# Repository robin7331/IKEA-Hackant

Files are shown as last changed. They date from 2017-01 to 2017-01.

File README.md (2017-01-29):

# IKEA Hackant

A simple LIN slave attached to the stock controller board adds two memory buttons.
If you are interested in how this was developed check out my YouTube Tutorial

YouTube Tutorial (https://www.youtube.com/watch?v=AB75AxprXqQ "IKEA Bekant Table Hacking")

## Schematics

Simple schematics created with [Fritzing](http://fritzing.org/home/ "Fritzing").

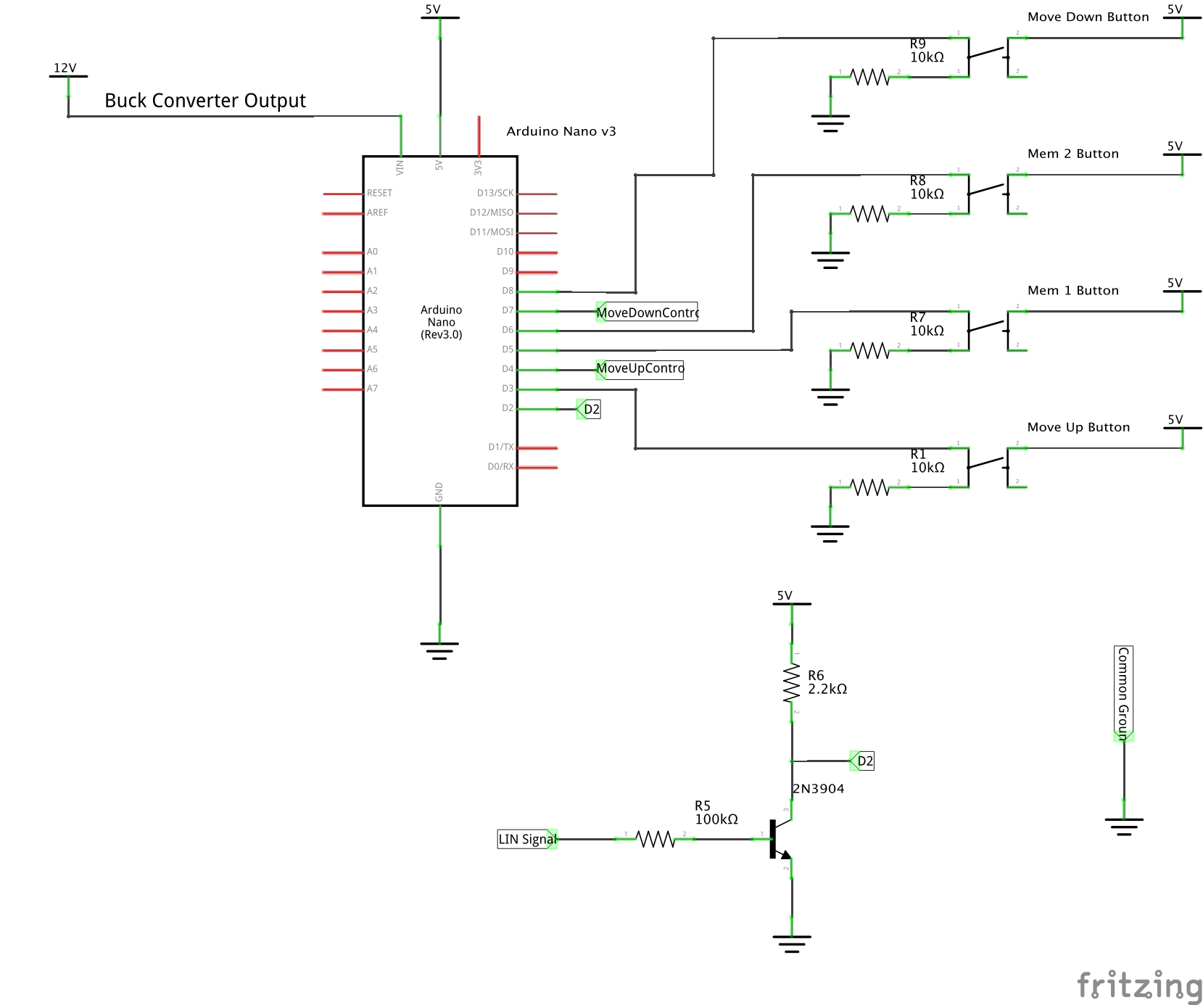
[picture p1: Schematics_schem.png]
Schematics

Board

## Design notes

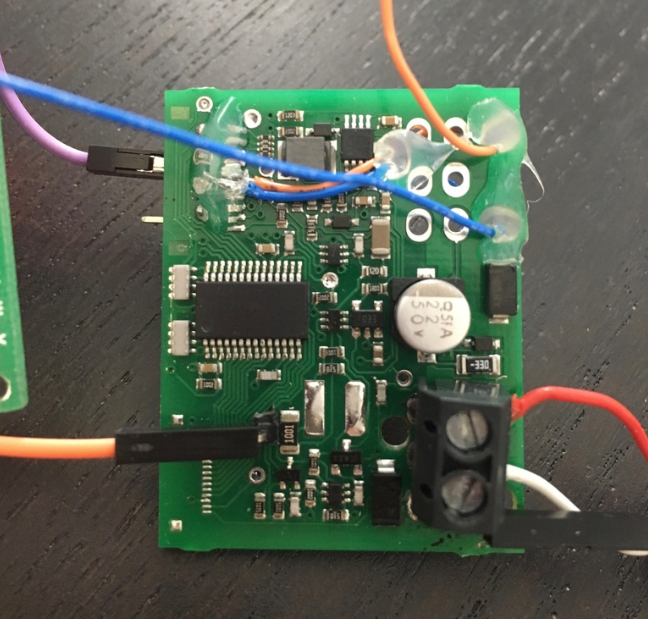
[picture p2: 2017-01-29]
Board.napkin/soup/E36C80D8-EE5A-4D45-80FC-AE3C89C8076F/imageData.tiff

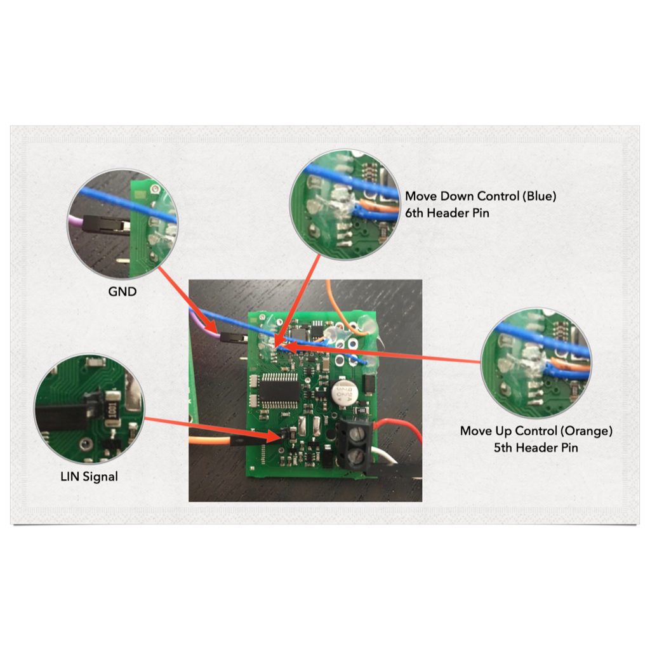
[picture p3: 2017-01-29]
Board.napkin/QuickLook/Thumbnail.png

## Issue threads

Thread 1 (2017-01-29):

Wiring

danmincu, 2017-01-29:
Please attach an image with the wiring of the Arduino to the LIN contoller.

robin7331, 2017-01-29:
Done. Check out the new Readme.
[Readme](https://github.com/robin7331/IKEA-Hackant)

Closed 2017-01-29.

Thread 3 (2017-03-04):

R6 prevents LIN packages to arrive

robertaramar, 2017-03-04:
Hi,

I have setup the hardware on a breadboard connected to the desk and I got everything working fine. However, I do NOT receive LIN frames when using R6 to pull-up the D2 line to 5V. Admittedly, I am using a different transistor. The one I had available is a BC547 instead of the 2N3904.

As I do not have enough background in electronics design, I that an issue? Is that caused by my different transistor?

Regards,

Robert

robertaramar, 2017-03-07:
End-User problem. BC547 - compared to 2N3904 - has E and C switched. So the transistor was wrongly inserted. Funnywise, it worked that way as long as I didn't insert the R6.
Problem solved.

Closed 2017-03-07.

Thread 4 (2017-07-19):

Buck Converter Voltage Rating

cgalford, 2017-07-19:
Have you put a scope or meter on the power line ("24V")? The power supply rests at ~24V but then ramps to ~35V when the desk is moving. My power supply went out so I've been trying to find an off the shelf solution. A generic 24V power supply results in very slow desk movement and a generic 36V matches the proper speed but without the slower ramp up.  It looks like you are using a MP1584EN converter which is rated to 28V input.

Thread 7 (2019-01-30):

No readings

prk3, 2019-01-30:
Hi. I am trying to hack my Bekant desk, but my Arduino isn't capturing any LIN frames. I tried connecting the wire, that normally goes to digital pin 2, to analog pin 2 and see what readings I would get. It turns out it constantly reads value 8 (sometimes 9). I think the voltage on LIN wire is too low to trigger frame detection. Do you have an idea what might be the cause?

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

I forgot to mention. The stock controller works fine, I can move the table without any problems.

prk3, 2019-04-27:
I either damaged the original controller while trying to hack it or did not consider different order of pins on the transistor I used (yours has EBC layout, mine had ECB).
At the end I decided to replace the controller completely. You can check it out [here](https://github.com/trainman419/bekant) (pictures and 3d case are yet to be added).
Thanks a lot for help!

Closed 2019-04-27.

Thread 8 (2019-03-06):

Can I use esp8266 to directly simulate button?

left4taco, 2019-03-06:
Hi, I'm thinking of using an ESP8266 to control the desk. Its GPIO pin can be set to either 3.3V or 0V.

Can I connect the pin directly to the button? So that I can set the GPIO to 0 to simulate the button being pushed, and reset it back to 3.3V when I want it to stop.

Thanks.

tg44, 2019-08-03:
I'm planning to do the same. I'm still searching for a good LIN lib to esp8266, but my idea is to hardwire a wemos D1 mini or a nodeMCU to it. My two concern right now is to find a LIN package to read the data, and if the current electronics can power a nodeMCU or not.

Had you any success?

slaesh, 2020-02-07:
hey there @left4taco and @tg44 .
i already did it, will publish my project soon.
including hardware and so on.. :)

will keep you updated..

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

alfonmga, 2020-04-12:
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

Hey @slaesh, did you publish it or not yet?

I would like to do it soon but  I don't have enough experience with projects like this one so I don't want to fuck it up lol.

BTW did you guys finally tried it? @left4taco @tg44

tg44, 2020-04-12:
Not yet. Still interested in this project, but I had no free-time to possibly brick my working table...

slaesh, 2020-05-10:
@alfonmga @tg44 not yet finished.. covid crashed my plans and results in some urgent projects to be done.. currently waiting for some parts shipped over the sea.. and trying to print a case..

hopefully i will be able to tinker in a few weeks! :)

keep you updated!

slaesh, 2020-06-29:
sorry for the long delay..
now created a project on tindie! :) @tg44 @alfonmga

https://www.tindie.com/products/slaesh/smart-ikea-bekant-controller-replacement-with-oled/

if you are interested, just join the list.. =)

meyerf93, 2020-07-28:
Hi @slaesh what you have done look really good. Could you give more details about the interface of the board ? (restAPI and Mqtt) how do you setup the connection wifi ?

algorni, 2021-05-26:
Does this hack works also for the RODULF standup desk?

CrazyDoge128, 2022-01-28:
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

I'm on the list for so long what's happening? Or could you make one for me? I'm from Czechia.

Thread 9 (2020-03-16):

GND

pwilms, 2020-03-16:
Awesome work, could you specify the GND PIN you soldered on the board? there are 5 holes in the back of the connector. which one is the correct one? in the middle?

Closed 2020-03-31.

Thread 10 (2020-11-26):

Implementing this with a Raspberry Pi

joubin, 2020-11-26:
Hey!

This is really great work. I’m not an EE, so following this was a bit hard for me. But... I was wondering how hard it would be convert your work to something that works on a Raspberry PI.

My thought is to use a Raspberry Pi + buttons as the controller. Then we can use something like [this](https://www.npmjs.com/package/homebridge-simple-http) on it. Then... I can say “Hey Siri, I want to sit” and the desk goes to the right position.

Let me know how unrealistic this is.

gcormier, 2021-01-30:
Two thoughts,

1. If you can find a LIN adapter for rPI, either USB, or one that runs off the GPIO's, you could write code to do so
2. You could interface with megadesk and use the newly added serial protocol https://github.com/gcormier/megadesk/issues/12

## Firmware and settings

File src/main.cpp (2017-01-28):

// Licensed under the Apache License, Version 2.0 (the "License");
// you may not use this file except in compliance with the License.
// You may obtain a copy of the License at
//
//    http://www.apache.org/licenses/LICENSE-2.0
//
// Unless required by applicable law or agreed to in writing, software
// distributed under the License is distributed on an "AS IS" BASIS,
// WITHOUT WARRANTIES OR CONDITIONS OF ANY KIND, either express or implied.
// See the License for the specific language governing permissions and
// limitations under the License.

#include <Arduino.h>
#include "avr_util.h"
#include "custom_defs.h"
#include "hardware_clock.h"
#include "io_pins.h"
#include "lin_processor.h"
#include "system_clock.h"
#include <EEPROM.h>


uint16_t lastPosition = 0;
uint16_t memOne = 0;
uint16_t memTwo = 0;

uint16_t currentTarget = 0;
uint8_t initializedTarget = false;
uint8_t targetThreshold = 0;
uint8_t currentTableMovement = 0;


const int moveTableUpPin = PD4;
const int moveTableDownPin = PD7;

const int moveUpButton = PD3;
const int moveM2Button = PD6;
const int moveM1Button = PD5;
const int moveDownButton = 8;

int pressedButton = 0;
int lastPressedButton = 0;
unsigned long lastPressed = 0;
uint8_t doOnce = false;


void printValues() {
  Serial.println("======= VALUES =======");
  Serial.print("Memory 1 is at: ");
  Serial.println(memOne);
  Serial.print("Memory 2 is at: ");
  Serial.println(memTwo);
  Serial.print("Threshold is: ");
  Serial.println(targetThreshold);
  Serial.print("Current Position: ");
  Serial.println(lastPosition);
  Serial.println("======================");
}

void printHelp() {
  Serial.println("======= Serial Commands =======");
  Serial.println("Send 'STOP' to stop");
  Serial.println("Send 'HELP' to show this view");
  Serial.println("Send 'VALUES' to show the current values");
  Serial.println("Send 'T123' to set the threshold to 123 (255 max!)");
  Serial.println("Send 'M1' to move to position stored in memory 1");
  Serial.println("Send 'M2' to move to position stored in memory 2");
  Serial.println("Send 'S1' to store current position in memory 1");
  Serial.println("Send 'S2' to store current position in memory 2");
  Serial.println("Send 'M15000' to move set the mem 1 position to 5000");
  Serial.println("Send 'M25000' to move set the mem 2 position to 5000");
  Serial.println("Send '1580' to move to position 1580.");
  Serial.println("===============================");
}

void storeM1(uint16_t value) {
  if (value > 150 && value < 6400) {
    memOne = value;
    Serial.print("New Memory 1: ");
    Serial.println(value);
    EEPROM.put(1, value);
  } else {
    Serial.println("Not stored. Keep your value between 150 and 6400");
  }
}

void storeM2(uint16_t value) {
  if (value > 150 && value < 6400) {
    memTwo = value;
    Serial.print("New Memory 2: ");
    Serial.println(value);
    EEPROM.put(3, value);
  } else {
    Serial.println("Not stored. Keep your value between 150 and 6400");
  }
}

void storeThreshold(uint8_t value) {
  if (value > 50 && value < 254) {
    targetThreshold = value;
    Serial.print("New Threshold: ");
    Serial.println(value);
    EEPROM.put(0, value);
  } else {
    Serial.println("Not stored. Keep your value between 50 and 254");
  }
}


// direction == 0 => Table stops
// direction == 1 => Table goes upwards
// direction == 2 => Table goes downwards
//
void moveTable(uint8_t direction) {
  if (direction != currentTableMovement) {
    currentTableMovement = direction;
    if (direction == 0) {
      Serial.println("Table stops");
      digitalWrite(moveTableUpPin, HIGH);
      digitalWrite(moveTableDownPin, HIGH);
    } else if (direction == 1) {
      Serial.println("Table goes up");
      digitalWrite(moveTableDownPin, HIGH);
      digitalWrite(moveTableUpPin, LOW);
    } else {
      Serial.println("Table goes down");
      digitalWrite(moveTableUpPin, HIGH);
      digitalWrite(moveTableDownPin, LOW);
    }
  }
}

// direction == 0 => Table is levelled
// direction == 1 => Target is above table
// direction == 2 => Target is below table
uint8_t desiredTableDirection() {

  int distance = lastPosition - currentTarget;
  uint16_t absDistance = abs(distance);

  if (absDistance > targetThreshold) {
    if (distance <= 0) { // table has to move up
      return 1;
    }
    return 2;
  }
  return 0;

}


void processLINFrame(LinFrame frame) {
  // Get the first byte which is the LIN ID
  uint8_t id = frame.get_byte(0);

  // 0x92 is the ID of the LIN node that sends the table position
  if (id == 0x92) {

    // the table position is a two byte value. LSB is sent first.
    uint8_t varA = frame.get_byte(2); //1st byte of the value (LSB)
    uint8_t varB = frame.get_byte(1); //2nd byte (MSB)
    uint16_t temp = 0;

    temp = varA;
    temp <<= 8;
    temp = temp | varB;

    if (temp != lastPosition) {
      lastPosition = temp;
      String myString = String(temp);
      char buffer[5];
      myString.toCharArray(buffer, 5);
      Serial.print("Current Position: ");
      Serial.println(buffer);

      if (initializedTarget == false) {
        currentTarget = temp;
        initializedTarget = true;
      }
    }

  }
}

void readButtons() {

  if (digitalRead(moveUpButton) == HIGH) {

    pressedButton = moveUpButton;
    if (lastPressedButton != pressedButton) {
      Serial.println("Button UP Pressed");
      lastPressedButton = pressedButton;
    }
    return;
  }

  if (digitalRead(moveM1Button) == HIGH) {
    pressedButton = moveM1Button;
    if (lastPressedButton != pressedButton) {
      Serial.println("Button M1 Pressed");
      lastPressedButton = pressedButton;

    }
    return;
  }

  if (digitalRead(moveM2Button) == HIGH) {
    pressedButton = moveM2Button;
    if (lastPressedButton != pressedButton) {
      Serial.println("Button M2 Pressed");
      lastPressedButton = pressedButton;

    }
    return;
  }

  if (digitalRead(moveDownButton) == HIGH) {
    pressedButton = moveDownButton;
    if (lastPressedButton != pressedButton) {
      Serial.println("Button DN Pressed");
      lastPressedButton = pressedButton;
    }
    return;
  }


  pressedButton = 0;

}

void loopButtons() {

  if (pressedButton != 0) {

    if (lastPressedButton == moveUpButton) {
      moveTable(1);
      currentTarget = lastPosition + (targetThreshold * 2);
    } else if (lastPressedButton == moveDownButton) {
      moveTable(2);
      currentTarget = lastPosition - (targetThreshold * 2);
    } else {
      if (doOnce == false) {
        lastPressed = millis();
        doOnce = true;
      }
    }

  } else {

    if (doOnce) {

      unsigned int pressDuration = millis() - lastPressed;

      if (pressDuration > 0 && pressDuration < 1000) { // short press

        Serial.print("Button pressed for ");
        Serial.print(pressDuration);
        Serial.println(" ms.");

        if (lastPressedButton == moveM1Button) {
          currentTarget = memOne;
        } else if (lastPressedButton == moveM2Button) {
          currentTarget = memTwo;
        }

      } else if (pressDuration >= 1000) {

        Serial.print("Button pressed for ");
        Serial.print(pressDuration);
        Serial.println(" ms.");

        if (lastPressedButton == moveM1Button) {
          storeM1(lastPosition);
        } else if (lastPressedButton == moveM2Button) {
          storeM2(lastPosition);
        }

      }

    }


    doOnce = false;
  }

}


void setup() {


  Serial.begin(115200);
  while (!Serial) {;};

  Serial.println("IKEA Hackant v1.0");
  Serial.println("Type 'HELP' to display all commands.");

  pinMode(moveTableUpPin, OUTPUT);
  pinMode(moveTableDownPin, OUTPUT);

  pinMode(moveUpButton, INPUT);
  pinMode(moveDownButton, INPUT);
  pinMode(moveM1Button, INPUT);
  pinMode(moveM2Button, INPUT);

  Serial.print("moveUpButton ");
  Serial.println(moveUpButton);
  Serial.print("moveDownButton ");
  Serial.println(moveDownButton);
  Serial.print("moveM1Button ");
  Serial.println(moveM1Button);
  Serial.print("moveM2Button ");
  Serial.println(moveM2Button);

  digitalWrite(moveTableUpPin, HIGH);
  digitalWrite(moveTableDownPin, HIGH);

  // setup everything that the LIN library needs.
  hardware_clock::setup();
  lin_processor::setup();

  // Enable global interrupts.
  sei();




  EEPROM.get(0, targetThreshold);
  if (targetThreshold == 255) {
    storeThreshold(120);
  }

  EEPROM.get(1, memOne);
  if (memOne == 65535) {
    storeM1(3500);
  }


  EEPROM.get(3, memTwo);
  if (memTwo == 65535) {
    storeM2(3500);
  }

  printValues();

}



void loop() {


  // Periodic updates.
  system_clock::loop();


  // Handle recieved LIN frames.
  LinFrame frame;

  // if there is a LIN frame
  if (lin_processor::readNextFrame(&frame)) {
    processLINFrame(frame);
  }

  // direction == 0 => Table is levelled
  // direction == 1 => Target is above table
  // direction == 2 => Target is below table
  uint8_t direction = desiredTableDirection();
  moveTable(direction);


  if (Serial.available() > 0) {

    // read the incoming byte:
    String val = Serial.readString();

    if (val.indexOf("HELP") != -1 || val.indexOf("help") != -1) {
      printHelp();
    } else if (val.indexOf("VALUES") != -1 || val.indexOf("values") != -1) {
      printValues();
    } else if (val.indexOf("STOP") != -1 || val.indexOf("stop") != -1) {

      if (direction == 1)
        currentTarget = lastPosition + (targetThreshold * 2);
      else if (direction == 2)
        currentTarget = lastPosition - (targetThreshold * 2);

      Serial.print("STOP at ");
      Serial.println(currentTarget);


    } else if (val.indexOf('T') != -1 || val.indexOf("t") != -1) {
      uint8_t threshold = (uint8_t)val.substring(1).toInt();
      storeThreshold(threshold);

    } else if (val.indexOf("M1") != -1 || val.indexOf("m1") != -1) {

      if (val.length() == 2) {
        currentTarget = memOne;
      } else {
        storeM1(val.substring(2).toInt());
      }


    } else if (val.indexOf("M2") != -1 || val.indexOf("m2") != -1) {

      if (val.length() == 2) {
        currentTarget = memTwo;
      } else {
        storeM2(val.substring(2).toInt());
      }

    } else if (val.indexOf("S1") != -1 || val.indexOf("s1") != -1) {

      storeM1(lastPosition);

    } else if (val.indexOf("S2") != -1 || val.indexOf("s2") != -1) {

      storeM2(lastPosition);

    } else {
      if (val.toInt() > 150 && val.toInt() < 6400) {
        Serial.print("New Target ");
        Serial.println(val);
        currentTarget = val.toInt();
      } else {
        Serial.println("Not stored. Keep your value between 150 and 6400");
      }
    }
  }

  readButtons();
  loopButtons();

}

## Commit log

2017-01-29 Updated Readme and added the Fritzing file
    [Schematics.fzz]
2017-01-29 Added a Board explanation
2017-01-29 Updated Fritzing
    [Schematics.fzz]
2025-05-26 Store currentTarget in EEPROM
